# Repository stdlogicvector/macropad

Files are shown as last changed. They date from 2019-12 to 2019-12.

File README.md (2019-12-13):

# MacroPad

A custom built 3x4 key macropad with encoders.

More Info on this Reddit Thread

## Circuit Board

Populated Circit Board - Bottom Side

The circuit board is designed in Eagle.
For easy manufacturing, the gerber-files and SMT production files are included.

The BOM and SMT placement file (CPL) are formatted for use with JLCPCB.

Apart from the keys, encoders, the USB-connector and the LED matrix driver all parts can be populated by JLCPCB.
The schematic contains the LCSC partnumbers in the attributes of each part.

### Keys

All keys compatible with Cherry MX 2 or 3 pin should fit the board.

### Encoders

The encoders a standard rotary encoders, just search ebay/aliexpress/amazon or your local electronics dealer.

## QMK Configuration

The folder qmk_config contains the configuration and code to build QMK for the NumPad.
Just put this folder in qmk/keyboards and run

```
make macropad/v1:default
```	
	
## Case

MacroPad with 3D printed case

The case can be 3D printed in two parts.
There are holes for heat-set M3 threaded inserts to hold the PCB and M2 threaded inserts to hold the plate.

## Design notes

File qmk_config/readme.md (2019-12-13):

MacroPad
===

MacroPad

-=-=-=-=-=-=-=-=-=-=-=-=-=-=-=-

A 12 key macro-pad with 2 rotary encoders.

Supports MX switches with LEDs.

Optional "Reset" switch can be used on the PCB.

-=-=-=-=-=-=-=-=-=-=-=-=-=-=-=-

Make example for this keyboard (after setting up your build environment):

    make macropad/v1:default

See [build environment setup](https://docs.qmk.fm/#/getting_started_build_tools) then the [make instructions](https://docs.qmk.fm/#/getting_started_make_guide) for more information.

-=-=-=-=-=-=-=-=-=-=-=-=-=-=-=-

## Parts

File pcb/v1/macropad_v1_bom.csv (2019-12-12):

Comment | Designator | Footprint | LCSC
1N4148W | D1, D2, D3, D4, D5, D6, D7, D8, D9, D10, D11, D12, D13, D14 | SOD-123 | C81598
1uF | C6, C7 | 0603_C | C15849
10k | R1, R2, R3, R4, R5, R6, R7, R8, R9 | 0603_R | C25804
10nF | C1, C2, C3, C4 | 0603_C | C57112
10uF | C12 | 0603_C | C19702
12pF | C8, C9 | 0603_C | C38523
16MHz | X1 | SMD-3225_4P | C13738
20k | R10, R11, R14, R15 | 0603_R | C4184
22R | R12, R13 | 0603_R | C23345
100nF | C5, C10 | 0603_C | C14663
ATMEGA32U4-MU | IC1 | QFN-44_EP_7x7x0.5P | C112161
B5819W | D15 | SOD-123 | C8598

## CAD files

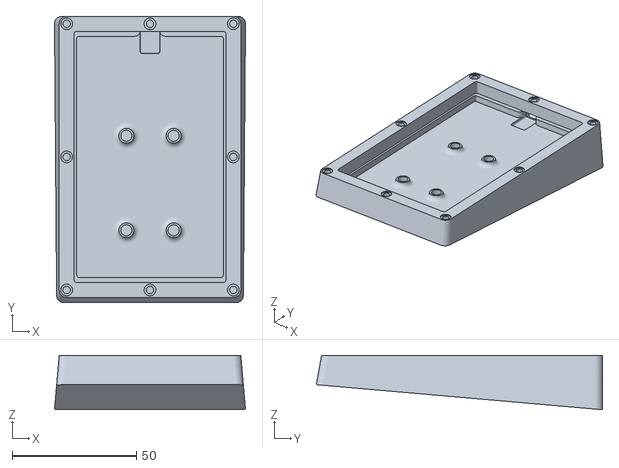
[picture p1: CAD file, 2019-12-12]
case/Case.stl
76.8 x 115.1 x 21.9

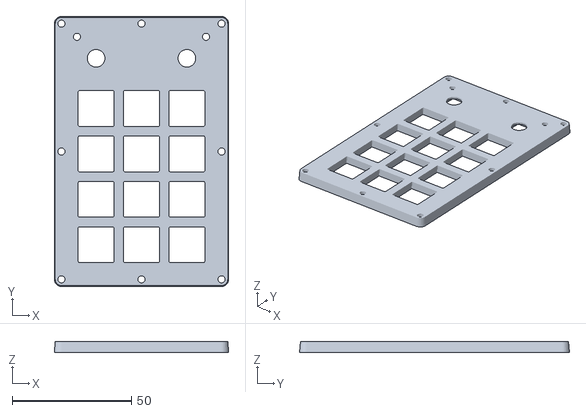
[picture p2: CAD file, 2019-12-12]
case/Cover.stl
73.0 x 113.0 x 4.50

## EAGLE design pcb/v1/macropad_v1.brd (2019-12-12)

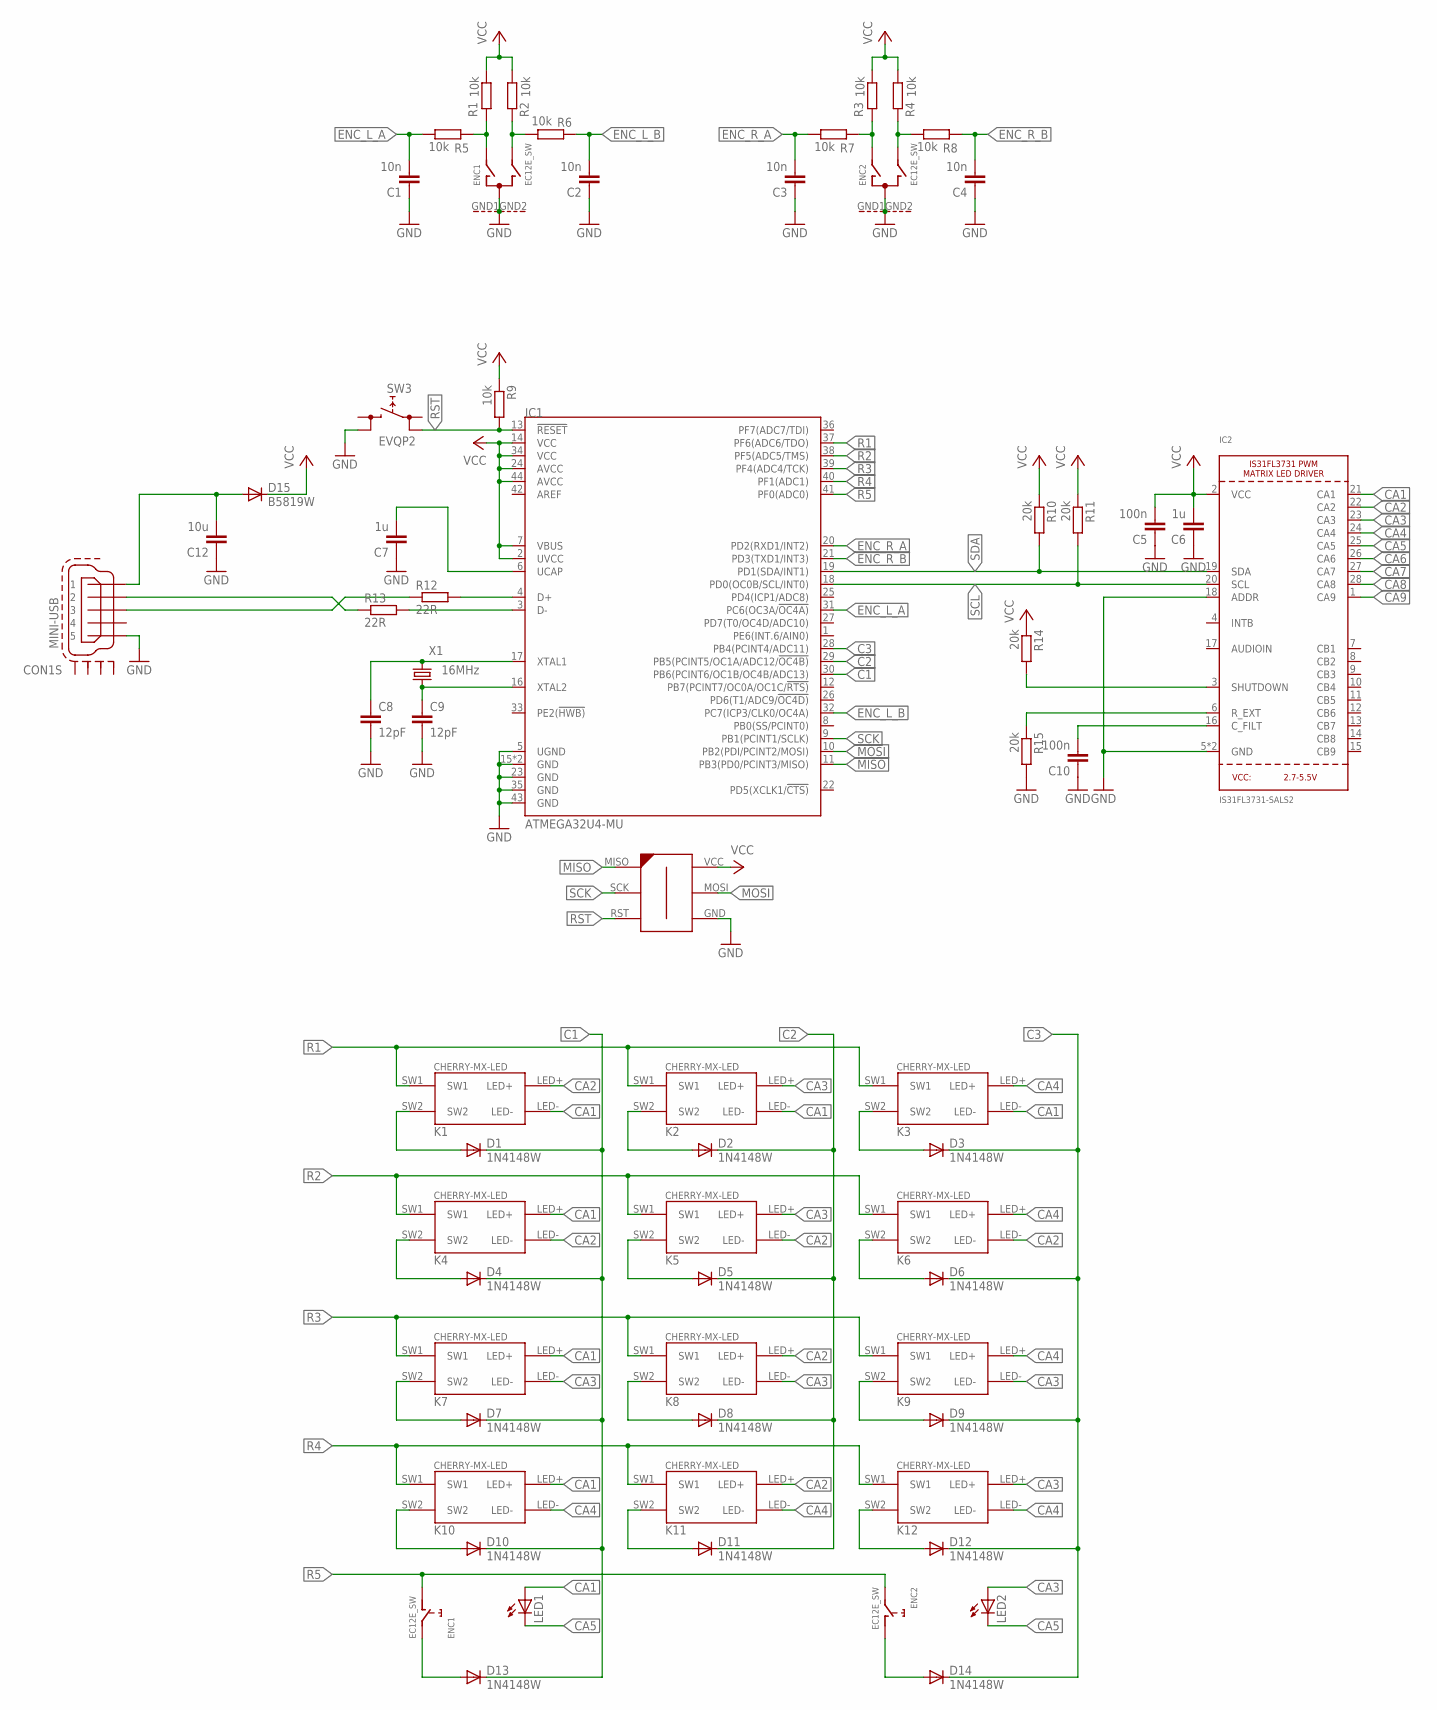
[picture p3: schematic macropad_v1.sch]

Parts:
C1, C2, C3, C4: 10n; C0603; LCSC C57112
C5, C10: 100n; C0603; LCSC C14663
C6, C7: 1u; C0603; LCSC C15849
C8, C9: 12pF; C0603; LCSC C38523
C12: 10u; C0603; LCSC C19702
CON1: MINI-USB; 32005-201
D1, D2, D3, D4, D5, D6, D7, D8, D9, D10, D11, D12, D13, D14: 1N4148W; SOD123; LCSC C81598
D15: B5819W; SOD123; LCSC C8598
ENC1, ENC2: EC12E_SW; ALPS_EC12E_SW
IC1: ATMEGA32U4-MU; QFN44G-0.5-7X7MM; LCSC C112161
IC2: IS31FL3731-SALS2; QFN28_4MM_0.4MM
K1, K2, K3, K4, K5, K6, K7, K8, K9, K10, K11, K12: CHERRY-MX-LED
LED1, LED2: LED3MM
R1, R2, R3, R4, R5, R6, R7, R8, R9: 10k; R0603; LCSC C25804
R10, R11, R14, R15: 20k; R0603; LCSC C4184
R12, R13: 22R; R0603; LCSC C23345
SW3: EVQP2; FARNELL 2079559
U$1: AVR-ISP-6-EDGE; 6PAD_ISP
X1: 16MHz; 3.2X2.5_KX-7; LCSC C13738

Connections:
C1: D1.C, D4.C, D7.C, D10.C, D13.C, IC1.30 (PB6(PCINT6/OC1B/OC4B/ADC13))
C2: D2.C, D5.C, D8.C, D11.C, IC1.29 (PB5(PCINT5/OC1A/ADC12/!OC4B))
C3: D3.C, D6.C, D9.C, D12.C, D14.C, IC1.28 (PB4(PCINT4/ADC11))
CA1: IC2.21 (CA1), K1.LED-, K2.LED-, K3.LED-, K4.LED+, K7.LED+, K10.LED+, LED1.A
CA2: IC2.22 (CA2), K1.LED+, K4.LED-, K5.LED-, K6.LED-, K8.LED+, K11.LED+
CA3: IC2.23 (CA3), K2.LED+, K5.LED+, K7.LED-, K8.LED-, K9.LED-, K12.LED+, LED2.A
CA4: IC2.24 (CA4), K3.LED+, K6.LED+, K9.LED+, K10.LED-, K11.LED-, K12.LED-
CA5: IC2.25 (CA5), LED1.K (C), LED2.K (C)
CA6: IC2.26 (CA6)
CA7: IC2.27 (CA7)
CA8: IC2.28 (CA8)
CA9: IC2.1 (CA9)
ENC_L_A: C1.2, IC1.31 (PC6(OC3A/!OC4A)), R5.1
ENC_L_B: C2.2, IC1.32 (PC7(ICP3/CLK0/OC4A)), R6.2
ENC_R_A: C3.2, IC1.20 (PD2(RXD1/INT2)), R7.1
ENC_R_B: C4.2, IC1.21 (PD3(TXD1/INT3)), R8.2
GND: C1.1, C2.1, C3.1, C4.1, C5.1, C6.1, C7.1, C8.2, C9.2, C10.1, C12.1, CON1.5, ENC1.C, ENC1.GND1 (G), ENC1.GND2 (G), ENC2.C, ENC2.GND1 (G), ENC2.GND2 (G), IC1.5 (UGND), IC1.15 (GND), IC1.23 (GND), IC1.35 (GND), IC1.43 (GND), IC1.TAB (GND), IC2.5 (GND), IC2.18 (ADDR), IC2.THERMAL (GND), R15.2, SW3.2 (1), U$1.GND
MISO: IC1.11 (PB3(PD0/PCINT3/MISO)), U$1.MISO
MOSI: IC1.10 (PB2(PDI/PCINT2/MOSI)), U$1.MOSI
unnamed: D1.A, K1.SW2
unnamed: D4.A, K4.SW2
unnamed: D7.A, K7.SW2
unnamed: D10.A, K10.SW2
unnamed: D5.A, K5.SW2
unnamed: D2.A, K2.SW2
unnamed: D8.A, K8.SW2
unnamed: D11.A, K11.SW2
unnamed: D12.A, K12.SW2
unnamed: D9.A, K9.SW2
unnamed: D6.A, K6.SW2
unnamed: D3.A, K3.SW2
unnamed: IC1.4 (D+), R12.2
unnamed: IC1.3 (D-), R13.2
unnamed: CON1.2, R13.1
unnamed: CON1.3, R12.1
unnamed: C8.1, IC1.17 (XTAL1), X1.3 (2)
unnamed: C12.2, CON1.1, D15.A
unnamed: C9.1, IC1.16 (XTAL2), X1.1
unnamed: C7.2, IC1.6 (UCAP)
unnamed: IC2.6 (R_EXT), R15.1
unnamed: D13.A, ENC1.E (2)
unnamed: D14.A, ENC2.D (1)
unnamed: C10.2, IC2.16 (C_FILT)
unnamed: IC2.3 (SHUTDOWN), R14.2
unnamed: ENC1.A, R1.2, R5.2
unnamed: ENC2.A, R3.2, R7.2
unnamed: ENC1.B, R2.2, R6.1
unnamed: ENC2.B, R4.2, R8.1
R1: IC1.37 (PF6(ADC6/TDO)), K1.SW1, K2.SW1, K3.SW1
R2: IC1.38 (PF5(ADC5/TMS)), K4.SW1, K5.SW1, K6.SW1
R3: IC1.39 (PF4(ADC4/TCK)), K7.SW1, K8.SW1, K9.SW1
R4: IC1.40 (PF1(ADC1)), K10.SW1, K11.SW1, K12.SW1
R5: ENC1.D (1), ENC2.E (2), IC1.41 (PF0(ADC0))
RST: IC1.13 (!RESET), R9.2, SW3.3 (0), U$1.RST
SCK: IC1.9 (PB1(PCINT1/SCLK)), U$1.SCK
SCL: IC1.18 (PD0(OC0B/SCL/INT0)), IC2.20 (SCL), R11.2
SDA: IC1.19 (PD1(SDA/INT1)), IC2.19 (SDA), R10.2
VCC: C5.2, C6.2, D15.C, IC1.2 (UVCC), IC1.7 (VBUS), IC1.14 (VCC), IC1.24 (AVCC), IC1.34 (VCC), IC1.44 (AVCC), IC2.2 (VCC), R1.1, R2.1, R3.1, R4.1, R9.1, R10.1, R11.1, R14.1, U$1.VCC

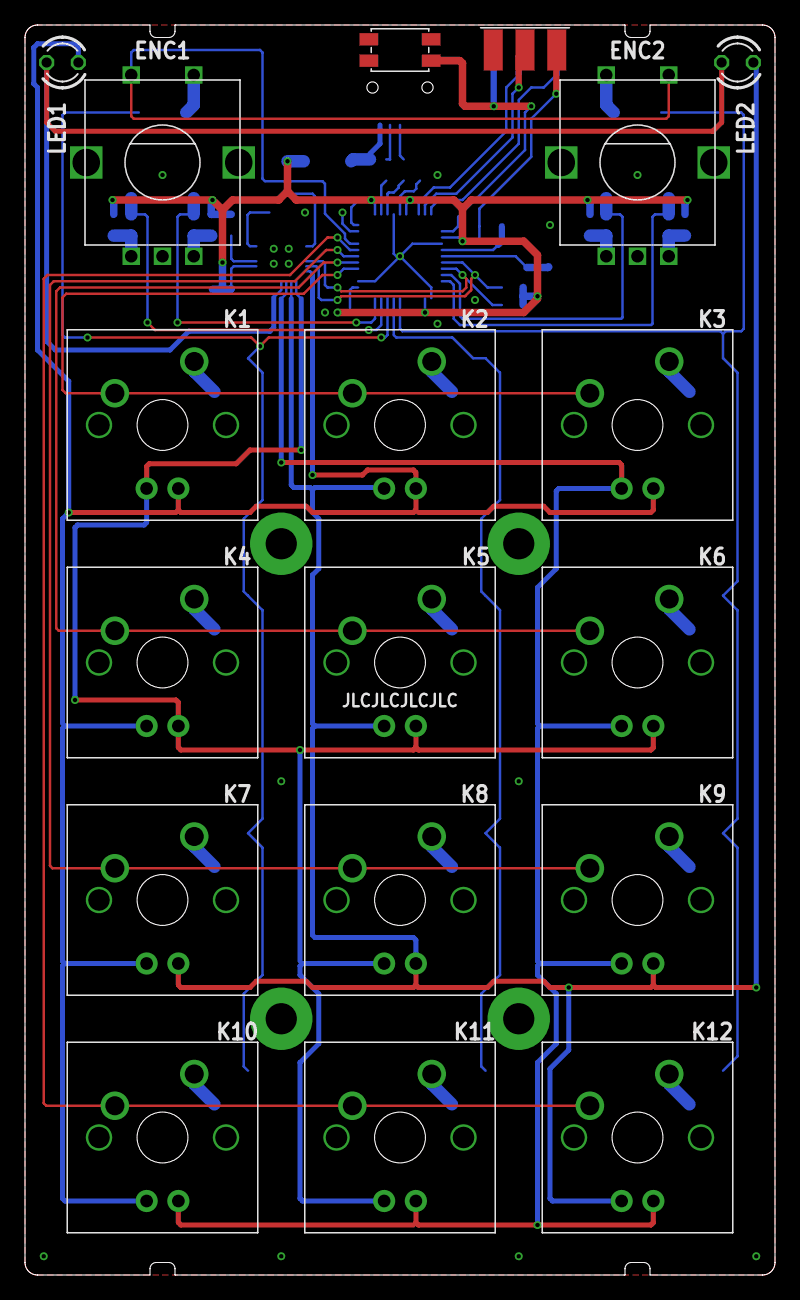
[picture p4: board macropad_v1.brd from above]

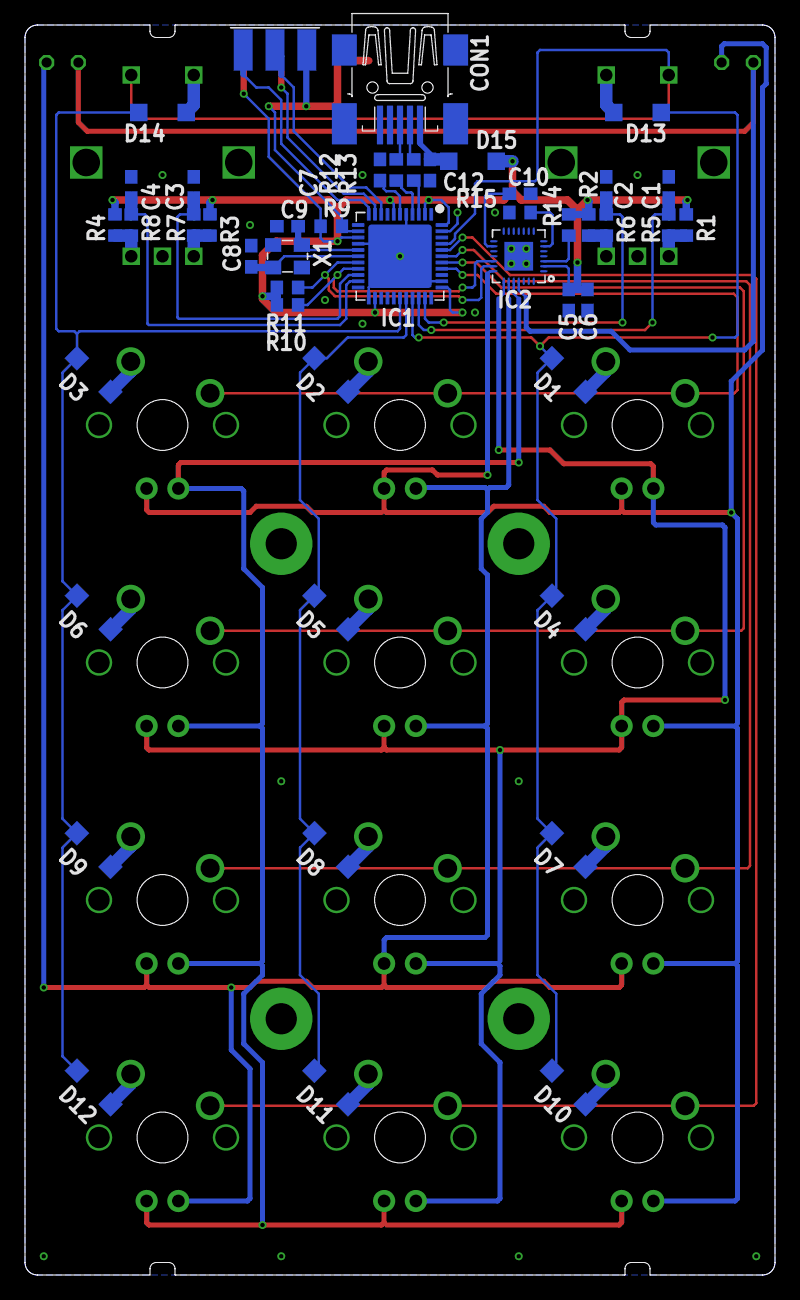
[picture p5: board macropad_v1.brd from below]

Board: 2 copper layers, 60.0 x 100.0 mm, 63 parts (46 on the bottom side), 54 nets.

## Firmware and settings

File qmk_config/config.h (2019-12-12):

/*
Copyright 2019 KW

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
You should have received a copy of the GNU General Public License
along with this program.  If not, see <http://www.gnu.org/licenses/>.
*/

#ifndef CONFIG_H
#define CONFIG_H

#include "config_common.h"

/* USB Device descriptor parameter */
#define VENDOR_ID       0xFEED
#define PRODUCT_ID      0x9000
#define MANUFACTURER    KW
#define PRODUCT         MacroPad
#define DESCRIPTION     Macropad with Encoders

/* key matrix size */
#define MATRIX_ROWS 5
#define MATRIX_COLS 3

/* COL2ROW or ROW2COL */
#define DIODE_DIRECTION ROW2COL

/* define if matrix has ghost */
//#define MATRIX_HAS_GHOST

/* Set 0 if debouncing isn't needed */
#define DEBOUNCE 5

/* Combo */
#define	TAPPING_TERM	200
#define COMBO_COUNT 	1

/* Mechanical locking support. Use KC_LCAP, KC_LNUM or KC_LSCR instead in keymap */
//#define LOCKING_SUPPORT_ENABLE
/* Locking resynchronize hack */
//#define LOCKING_RESYNC_ENABLE

#define LED_DRIVER_COUNT		1
#define LED_DRIVER_LED_COUNT	14
#define LED_DRIVER_ADDR_1		0b1110100	// 0x74 // AD-Pin to GND

#define BACKLIGHT_LEVELS 		8

#ifdef SUBPROJECT_v1
    #include "v1/config.h"
#endif

#endif

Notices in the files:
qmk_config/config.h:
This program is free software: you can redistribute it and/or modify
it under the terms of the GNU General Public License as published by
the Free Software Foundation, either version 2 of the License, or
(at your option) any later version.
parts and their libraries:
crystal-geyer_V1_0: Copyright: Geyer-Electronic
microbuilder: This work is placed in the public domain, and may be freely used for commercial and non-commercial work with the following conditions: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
